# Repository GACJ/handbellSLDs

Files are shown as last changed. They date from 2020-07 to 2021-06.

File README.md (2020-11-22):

# handbellSTLs
These STLs are the copyright of eBells (Ben Johnson, Tim Hart, Simon Gay and Graham John) and are provided under a Creative Commons Attribution-NonCommercial-ShareAlike 3.0 license (see license.txt) which permits their use for non-commercial purposes. 

STLs for 3D printing of dummy handbells that can be used with change ringing simulators.

90mm bell - support is needed for the button shafts and the electronics tunnel; print from same material as 3mm plug and electronics cap. 

Handle - support is needed for the overhang at the end of the square section, otherwise it tends to droop; print from same material as grommit and bell cap.

*22/11/2020 - Updated with v10 handle design with integrated cable clamp for rubber sleeved cable.

Bill of parts contains links to online suppliers

* Learning to Ring Handbells - https://www.handbellringing.co.uk/ - various blog entries on constructing your own dummy handbells
* Handbell Manager - https://handbellmanager.changeringing.co.uk/ - an interface between USB controllers and various ringing simulators, such as Abel, BelTower, RingingRoom and Muster
* Handbell Stadium - https://handbellstadium.org/ - a 3D simulator for changeringing on handbells that requires USB dummy handbells

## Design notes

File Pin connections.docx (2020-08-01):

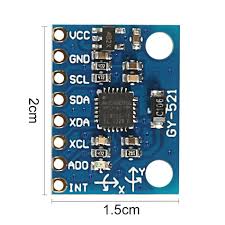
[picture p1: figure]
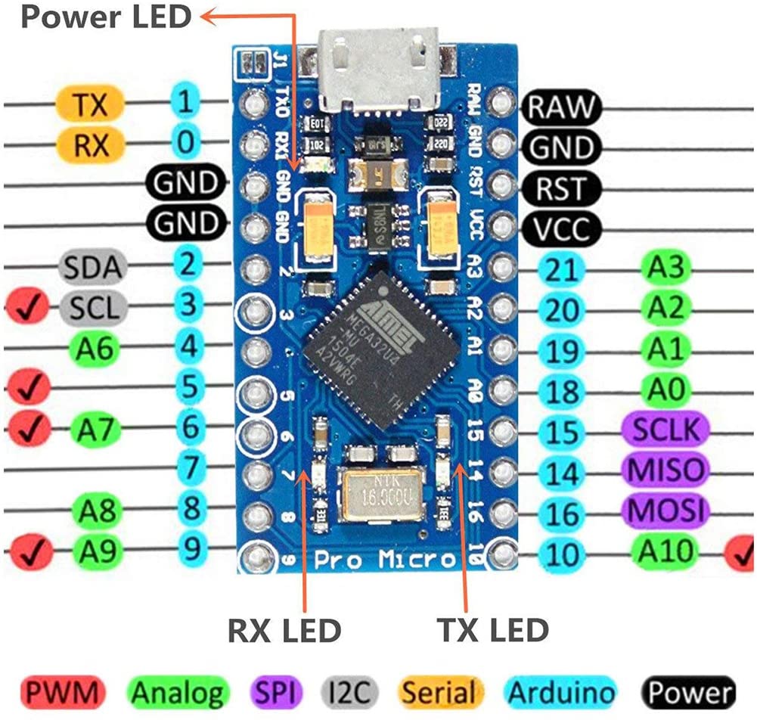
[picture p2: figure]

Pro Micro | | Wire colour
VCC | MPU 6050 - VCC | Red
Gnd (next to pin 2) | MPU 6050 - Gnd | Black
Pin 2 | MPU 6050 - SDA | White
Pin 3 | MPU6050 - SCL | Yellow
Gnd (next to pin 0) | Button 1 (either leg) | Black
Pin 9 | Button 1 (either leg) | Green
Gnd (inbetween RAW and RST) | Button 2 (either leg) | Black
Pin 10 | Button 2 (either leg) | Blue

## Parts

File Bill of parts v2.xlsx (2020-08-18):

Dummy Handbell cost (each)
 | Ind cost | Weight (g) | Quantity | Line Cost | Line Weight (g)
Electronics
Leonardo Pro Micro | £4.28 | 5 | 1 | £4.28 | 5 | https://www.ebay.co.uk/itm/Pro-Micro-ATMEGA32U4-Arduino-Compatible-Board-5V-16MHz-Micro-USB/283887665236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
MPU6050 | £2.79 | 1 | 1 | £2.79 | 1 | https://www.ebay.co.uk/itm/GY-521-3-Axis-Gyroscope-Accelerometer-Module-MPU-6050-I2C-ADC-Pi-Arduino/362440016674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
Switches | £1.74 | 1 | 2 | £3.48 | 2 | https://uk.farnell.com/multicomp/r13-24al-05-bb/switch-spst-3a-125v-tht/dp/1634693?CMP=i-ddd7-00001003
Jumper wires (4x 4cm, 4x 8cm) | £0.15 | 1 | 1 | £0.15 | 1 | https://www.amazon.co.uk/TUOFENG-Electric-Flexible-Different-Electronic/dp/B07V5FVSYL
Shrink wrap (3mm) | £0.10 | 0.5 | 4 | £0.40 | 2
Solder | £0.10 | 0.5 | 1 | £0.10 | 0.5
Epoxy | £0.50 | 0.5 | 1 | £0.50 | 0.5 | https://www.amazon.co.uk/Gorilla-6144000-Heavy-Duty-Weld/dp/B077XSW24S
micro USB to USB C adaptor | £2.50 | 1.5 | 1 | £2.50 | 1.5 | https://www.amazon.co.uk/gp/product/B071W8WQBD/ref=ppx_yo_dt_b_asin_title_o01_s00?ie=UTF8&psc=1
Bell
90mm bell, plug, electronics plug | £3.50 | 102 | 1 | £3.50 | 102 | https://www.amazon.co.uk/gp/product/B082XTFB7T/ref=ppx_yo_dt_b_asin_title_o00_s00?ie=UTF8&psc=1
50mm dia, 3mm thick, steel weight | £1.18 | 50 | 1 | £1.18 | 50 | https://www.ebay.co.uk/itm/Mild-Steel-Discs-Circles-Laser-Cut/301312965722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
8mm countersunk screws | £0.06 | 1 | 4 | £0.23 | 4 | https://www.amazon.co.uk/gp/product/B00SN3KF06/ref=ppx_yo_dt_b_asin_title_o05_s00?ie=UTF8&psc=1
Handle
Plastic handle + cap + grommit + switch buttons | £1.78 | 67 | 1 | £1.78 | 67 | https://www.amazon.co.uk/gp/product/B07MGKYFFP/ref=ppx_yo_dt_b_asin_title_o05_s00?ie=UTF8&psc=1
 |  |  |  |  |  | https://www.amazon.co.uk/gp/product/B07FQ75QG2/ref=ppx_yo_dt_b_search_asin_title?ie=UTF8&psc=1
USB Cable | £3.00 | 35 | 1 | £3.00 | 35 | https://www.amazon.co.uk/gp/product/B07WT36LPN/ref=ppx_yo_dt_b_asin_title_o01_s00?ie=UTF8&psc=1
 | Total Cost |  |  | £23.87

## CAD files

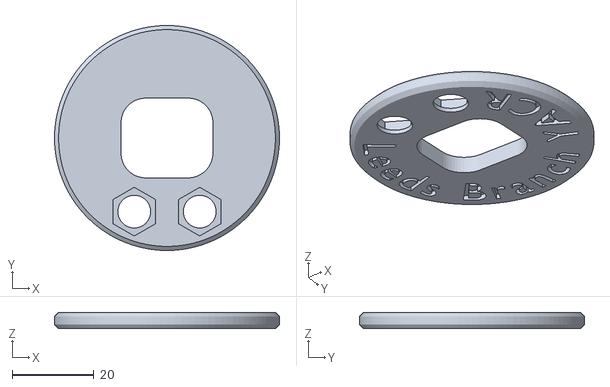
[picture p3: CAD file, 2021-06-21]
LeedsBranchEmbossed.stl
55.0 x 55.0 x 4.00

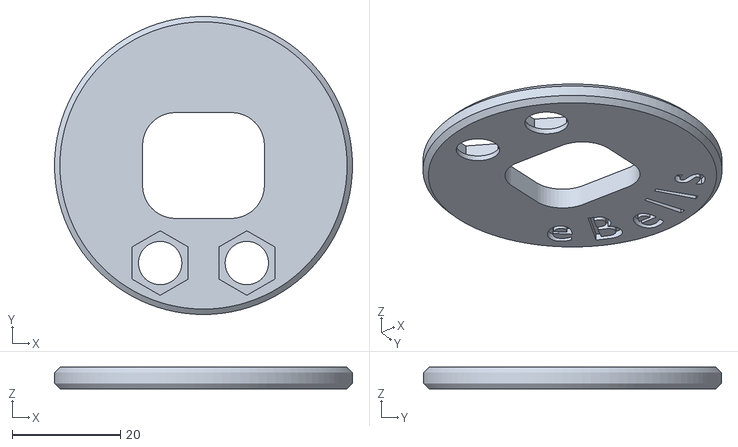
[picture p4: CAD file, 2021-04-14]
eBellsCapEmbossed.stl
55.0 x 55.0 x 4.00

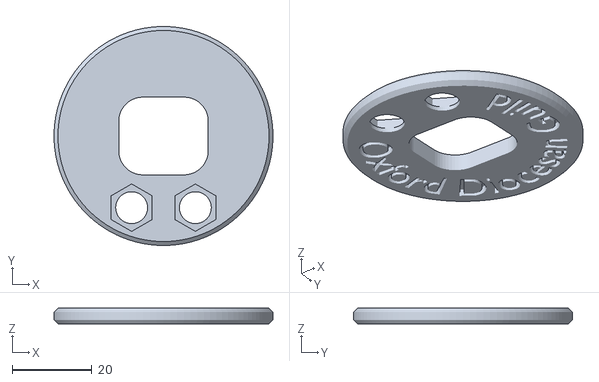
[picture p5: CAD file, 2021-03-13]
OxfordDiocesanGuildEmbossed.stl
55.0 x 55.0 x 4.00

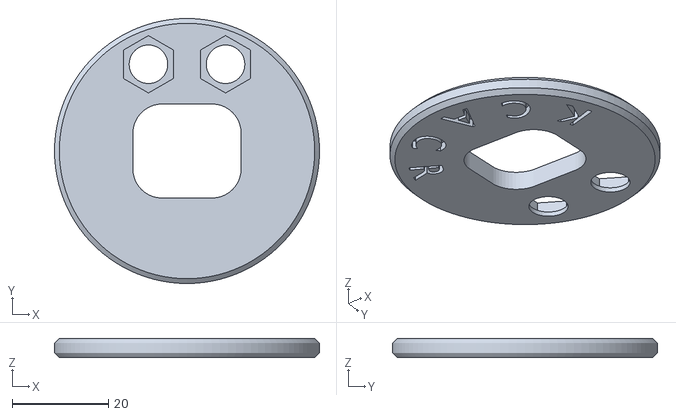
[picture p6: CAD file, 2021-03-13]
KCACRcapEmbossed.stl
55.0 x 55.0 x 4.00

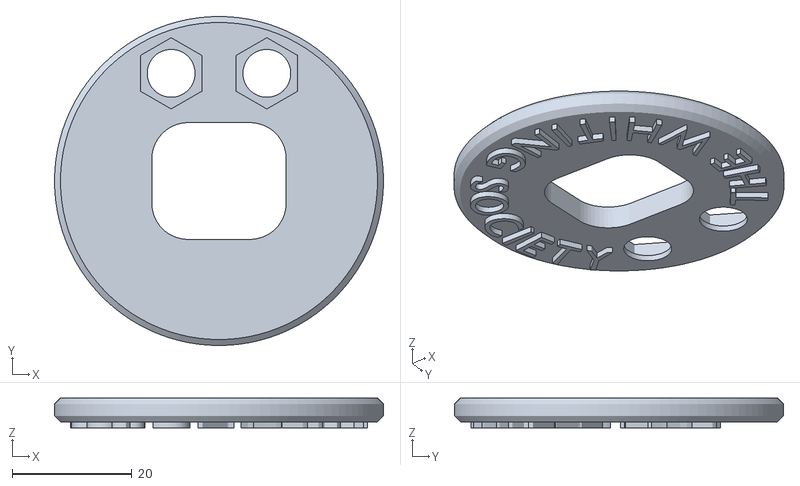
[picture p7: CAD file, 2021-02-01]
whitingcapraised.stl
55.0 x 55.0 x 5.01

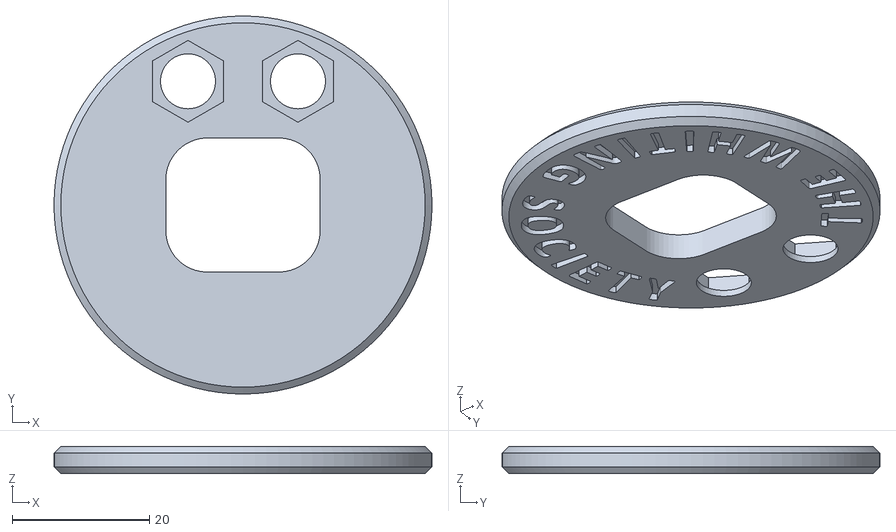
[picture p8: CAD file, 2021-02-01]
whitingcapembossed.stl
55.0 x 55.0 x 4.00

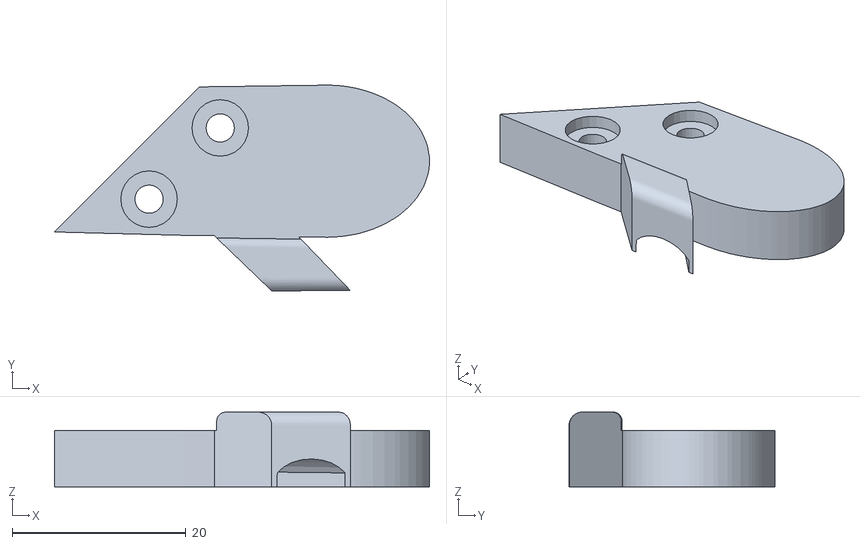
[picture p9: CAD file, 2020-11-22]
wire clip v10V3.stl
43.1 x 23.7 x 8.60

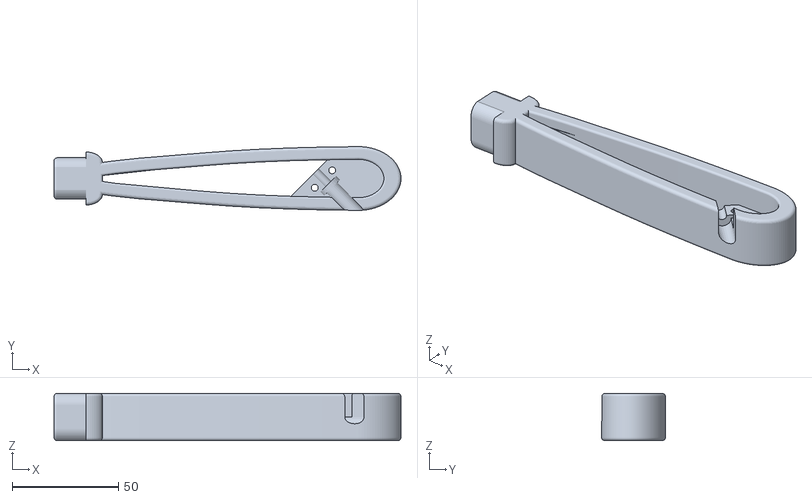
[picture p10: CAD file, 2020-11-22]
handle v10V3.stl
163.1 x 30.0 x 22.2

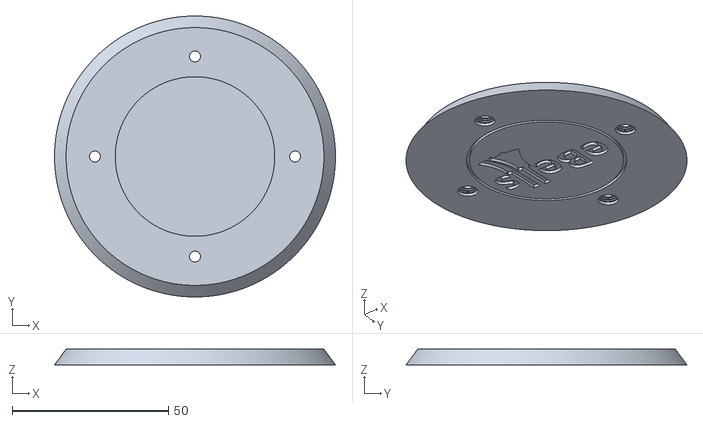
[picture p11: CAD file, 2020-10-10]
90mm dia, 3mm deep plug v2.stl
89.9 x 89.8 x 5.00

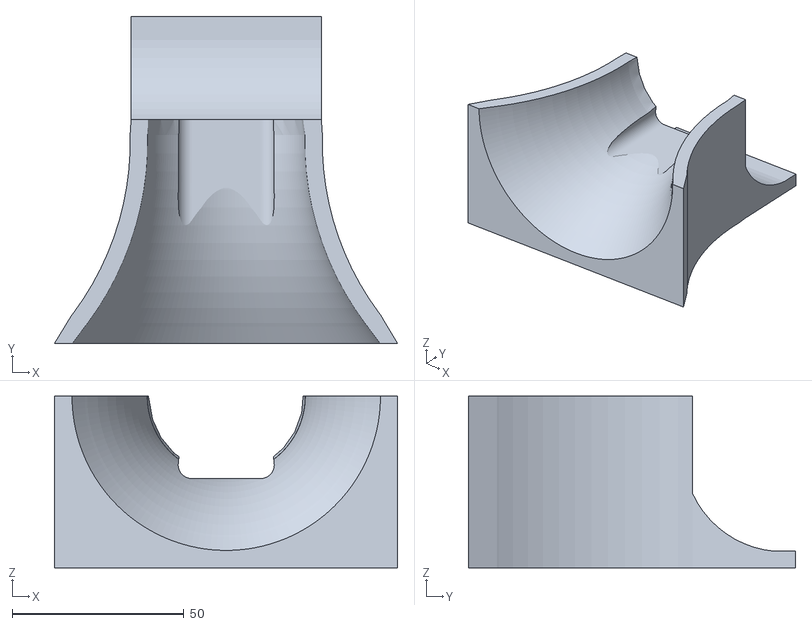
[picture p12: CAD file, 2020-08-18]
Calibration mount.stl
100.0 x 95.3 x 50.0

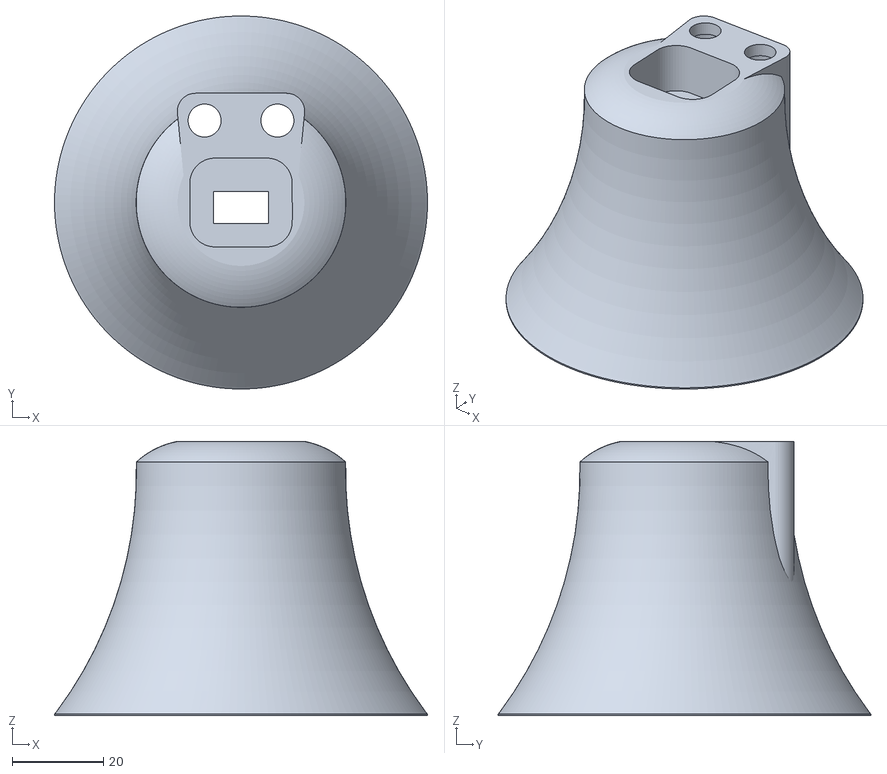
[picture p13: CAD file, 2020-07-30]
90mm dia, weighted for plastic handle.stl
81.9 x 81.9 x 60.3

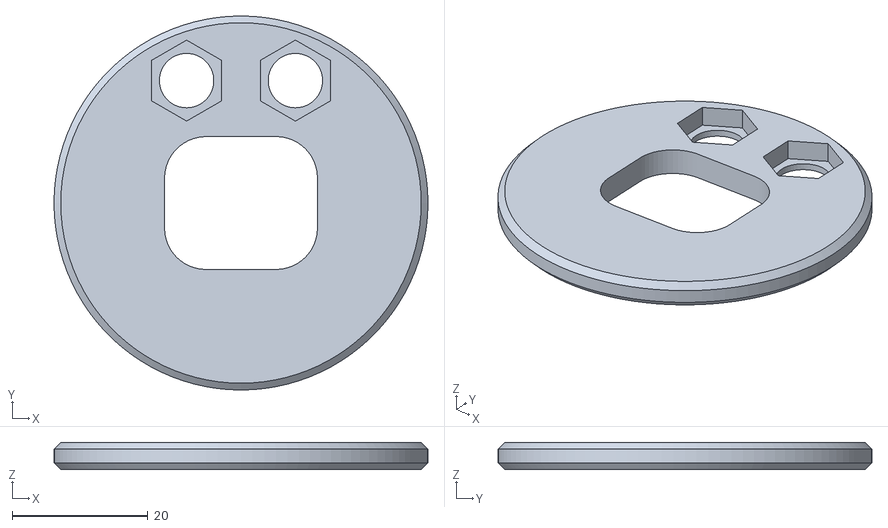
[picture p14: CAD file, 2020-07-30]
bell cap v7.stl
55.0 x 55.0 x 4.00

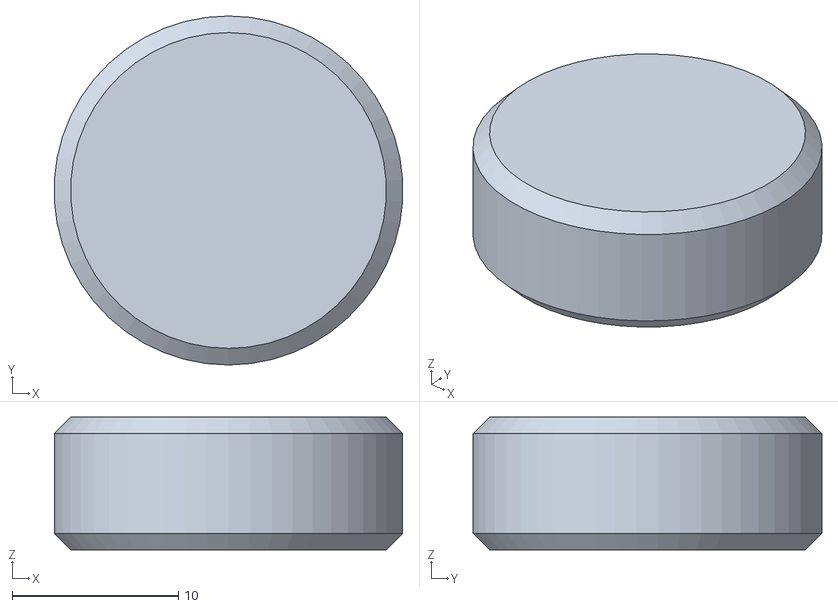
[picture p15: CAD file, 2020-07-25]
electronics plug.stl
21.0 x 21.0 x 8.00

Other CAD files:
ODGEmbossed.stl

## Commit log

2021-02-01 add whiting caps
    [whitingcapembossed.stl, whitingcapraised.stl]
2021-03-13 add lettered caps for KCACR and ODG
    [KCACRcapEmbossed.stl, ODGEmbossed.stl]
2021-03-13 add alternative ODG Cap
    [OxfordDiocesanGuildEmbossed.stl]
2021-04-14 add eBells cap
    [eBellsCapEmbossed.stl]
2021-06-21 alternative cap for Leeds Branch
    [LeedsBranchEmbossed.stl]
